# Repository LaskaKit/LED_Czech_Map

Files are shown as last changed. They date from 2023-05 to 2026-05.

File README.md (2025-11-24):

# Interaktivní LaskaKit LED Mapa ČR s adresovatelnými RGB LED

Domů, do zasedačky nebo do kanceláře, teplota nebo srážky, interaktivní mapa ČR s adresovatelnými RGB LED určitě překážky klást nebude. Měj přehled o aktuální situaci ať už je to teplota napříč Českou republikou nebo přicházející srážky, které pohodlně zobrazíš na této mapě. 

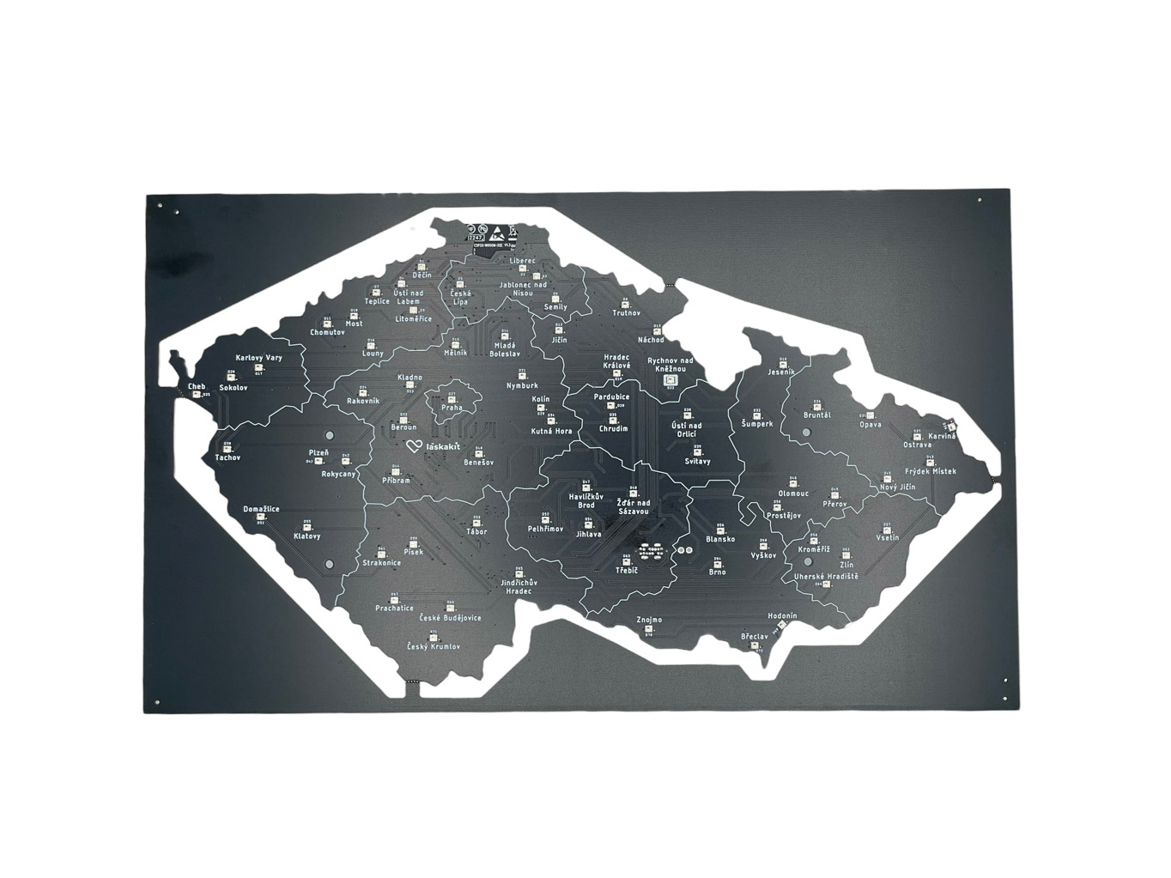
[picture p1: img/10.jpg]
Mapa


Na plošném spoji ve tvaru České republiky o velikosti cca 265x150mm najdeš desítky adresovatelných RGB LED, každá představuje jedno město v ČR.</br>
JSON: https://wiki.tmep.cz/doku.php?id=ruzne:led_mapa_okresu_cr

Seznam měst a pořadí RGB LED najdeš níže 
| LaskaKit ID | TMEP ID | Okres |
|:--:|:---:|:---|
| 25	| 1	| Cheb |
| 20	| 2	| Sokolov |
| 17	| 3	| Karlovy Vary |
| 11	| 4	| Chomutov |
| 16	| 5	| Louny |
| 10	| 6	| Most |
| 7	| 7 | Teplice |
| 9	| 8 | Litoměřice |
| 4	| 9 | Ústí nad Labem |
| 1 | 10 | Děčín |
| 5 | 11 | Česká Lípa |
| 2 | 12 | Liberec |
| 3 | 13 | Jablonec nad Nisou |
| 6 | 14 | Semily |
| 12 | 15 | Jičín |
| 8 | 16 | Trutnov |
| 13 | 17 | Náchod |
| 19 | 18 | Hradec Králové |
| 22 | 19 | Rychnov nad Kněžnou |
| 30 | 20 | Ústí nad Orlicí |
| 28 | 21 | Pardubice |
| 35 | 22 | Chrudim |
| 39 | 23 | Svitavy |
| 32 | 24 | Šumperk |
| 18 | 25 | Jeseník |
| 26 | 26 | Bruntál |
| 46 | 27 | Olomouc |
| 31 | 28 | Opava |
| 37 | 29 | Ostrava-město |
| 36 | 30 | Karviná |
| 43 | 31 | Frýdek-Místek |
| 45 | 32 | Nový Jičín |
| 57 | 33 | Vsetín |
| 49 | 34 | Přerov |
| 62 | 35 | Zlín |
| 58 | 36 | Kroměříž |
| 66 | 37 | Uherské Hradiště |
| 69 | 38 | Hodonín |
| 60 | 39 | Vyškov |
| 50 | 40 | Prostějov |
| 56 | 41 | Blansko |
| 64 | 42 | Brno-město |
| xx | 43 | Brno-venkov |
| 72 | 44 | Břeclav |
| 70 | 45 | Znojmo |
| 63 | 46 | Třebíč |
| 48 | 47 | Žďár nad Sázavou |
| 54 | 48 | Jihlava |
| 47 | 49 | Havlíčkův Brod |
| 52 | 50 | Pelhřimov |
| 65 | 51 | Jindřichův Hradec |
| 53 | 52 | Tábor |
| 68 | 53 | České Budějovice |
| 71 | 54 | Český Krumlov |
| 67 | 55 | Prachatice |
| 61 | 56 | Strakonice |
| 59 | 57 | Písek |
| 55 | 58 | Klatovy |
| 51 | 59 | Domažlice |
| 38 | 60 | Tachov |
| xx | 61 | Plzeň-sever |
| 41 | 62 | Plzeň-město |
| xx | 63 | Plzeň-jih |
| 42 | 64 | Rokycany |
| 24 | 65 | Rakovník |
| 23 | 66 | Kladno |
| 15 | 67 | Mělník |
| 14 | 68 | Mladá Boleslav |
| 21 | 69 | Nymburk |
| 29 | 70 | Kolín |
| 34 | 71 | Kutná Hora |
| 40 | 72 | Benešov |
| 44 | 73 | Příbram |
| 33 | 74 | Beroun |
| xx | 75 | Praha-západ |
| xx | 76 | Praha-východ |
| 27 | 77 | Praha |

Deska na které je osazen Wi-Fi a Bluetooth modul ESP32 obsahuje navíc i [uŠup konektor](https://blog.laskakit.cz/predstavujeme-univerzalni-konektor-pro-propojeni-modulu-a-cidel-%CE%BCsup/) pro připojení nejrůznějších čidel.

A jaké moduly to mohou být? Třeba čidlo [SCD41 pro měření CO2, teploty a vlhkosti vzduchu](https://www.laskakit.cz/laskakit-scd41-senzor-co2--teploty-a-vlhkosti-vzduchu/), čidla SHT41 [teploty a vlhkosti vzduchu](https://www.laskakit.cz/laskakit-sht40-senzor-teploty-a-vlhkosti-vzduchu/) a [čidla tlaku, teploty a vlhkosti vzduchu BME280](https://www.laskakit.cz/arduino-senzor-tlaku--teploty-a-vlhkosti-bme280/), [RTC Hodiny reálného času](https://www.laskakit.cz/laskakit-ds3231-orig--rtc-hodiny-realneho-casu/) s DS3231 nebo [OLED displej o velikosti 1.3" a rozlišení 128x64px](https://www.laskakit.cz/laskakit-oled-displej-128x64-1-3--i2c/?variantId=11903).

Deska LaskaKit LED Mapa ČR má osazen i vlastní programátor a není tak třeba mačkat tlačítka proto, aby se ESP32 naprogramovalo. Prostě jen připojíš USB-C kabel s počítačem a klikneš na "Nahrát".</br>
GPIO pin, který ovládá adresovatelné RGB LED je číslo 25 na ESP32. Adresovatelné RGB LED jsou zapojeny za sebou a díky už napsaným knihovnám je ovládání LEDek naprostá hračka. </br>

Mapa má i čtyři upevňovací otvory a navíc i rozšiřující konektor pro připojení třeba OLED displeje nebo čehokoliv jiného.

Díky popularitě této mapy vznikly nejrůznější zajímavé projekty - zobrazení teplot ze služby [TMEP.cz](https://tmep.cz/) ([vzorový kód najdeš tady](https://github.com/LaskaKit/LED_Czech_Map/tree/main/SW/tmep_okresy-cr-teplota)) nebo zobrazení srážek na základě dat z radaru.</br>
Kód je opět [na našem github](https://github.com/LaskaKit/LED_Czech_Map/tree/main/SW/CHMI_srazky). Kód má navíc možnosti nastavení zobrazení. 
Jednoduché zobrazení (vybereme pouze dominantní barva) nebo možnost přidání animace, zobrazení srážek před 30 minutami, 20, 10 a aktuální radarový obraz.

A to rozhodně není všechno! S touto mapou si můžeš zahrát hru "[Zachraň město! (github)](https://github.com/LaskaKit/LED_Czech_Map/tree/main/SW/Hra_Zachran_Mesto)". Správnou odpovědí uhasíš hořící město, tou špatnou začne hořet jiné.
Jednoduchou instalaci programu dokážeš díky naší [webové instalační stránce](https://www.laskakit.cz/navody-ke-zbozi/).

Máš jiný nápad? Sem s ním!

Mapu můžeš zakoupit na https://www.laskakit.cz/laskakit-interaktivni-mapa-cr-ws2812b/

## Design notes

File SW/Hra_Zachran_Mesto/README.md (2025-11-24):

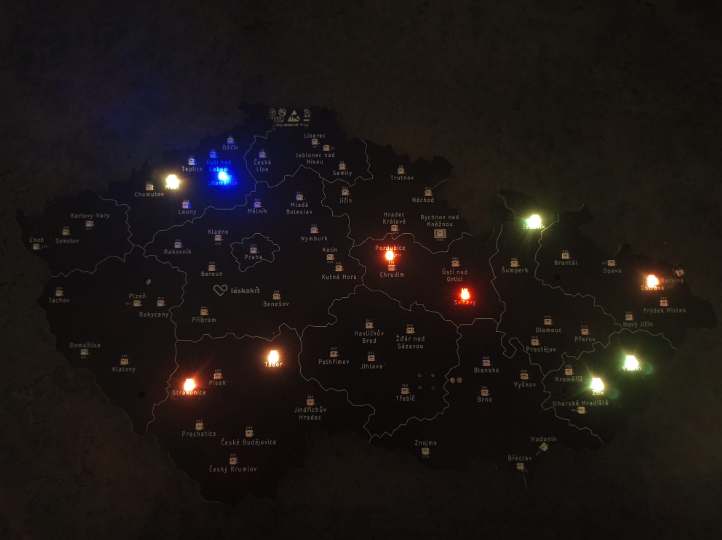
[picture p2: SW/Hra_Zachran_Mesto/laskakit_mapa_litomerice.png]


## Hra Zachraň město s vývojovou deskou Laskakit Interaktivní Mapa ČR

Tuto aplikaci jsme vytvořili jako zábavnou, interaktivní a naučnou hru pro použití s vývojovou deskou Laskakit Interaktivní Mapa ČR.

Hra začíná deseti městy, které jsou v plamenech a jen ty je můžeš zachránit! Ale pozor! Pokud odpovíš špatně, začne hořet další město!

### Využití
Využití této hry může být ve výuce na školách, kroužcích nebo třeba i mateřské škole, kde ovládat telefon bude učitel a odpovídat budou děti.
Položené otázky jsou jen ve vaší režii - jaké otázky tam zadáte, takové tam budete mít. Jediné, co je nutné, je dodržet formát otázek.
Chcete otázky ohledně matematiky pro první stupeň? Jasně! Zeměpis? Jasně! Čeština? Samozřejmě. 

Díky této interaktivní pomůcce může být i výuka zajímavější a zábavnější!

Tato aplikace využívá interaktivní mapu ČR od Laskakit.cz. Hráč na mobilním telefonu, tabletu nebo počítači musí skrze webový prohlížeč odpovídat na otázky, dokud neuhasí všechna města.

### Začátek hry

Po zapnutí vytvoří deska vlastní Access Point. Připoj se přes tvůj telefon k WiFi "LaskaKit_MapaCR", v prohlížeči zadej IP adresu 192.168.4.1. Tam můžeš zadat jméno a heslo k tvé WiFi.
Po restartu se ti v Serial Terminalu (Arduino, Yat, Putty; rychlost 115200 Bd) zobrazí přidělená IP adresa. V prohlížeči zadej tvou IP adresu a můžeš přidat otázky a začít hrát.

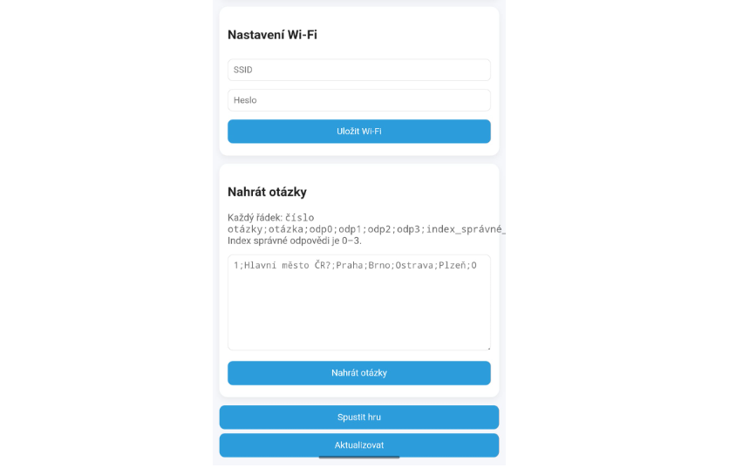
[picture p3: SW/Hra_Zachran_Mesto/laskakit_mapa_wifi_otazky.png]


Vývojová deska založená na ESP32 si otázky neukládá do trvalé paměti. Po každém restartu je nutné zadat sadu otázek. Čip si ale pamatuju zadané jméno a heslo k WiFi. 
Pokud se k ní nepřipojí, vytvoří si vlastní s názvem "Laskakit_MapaCR".

### Formát otázek
Číslo otázky; Otázka; Odpověď0; Odpověď1; Odpověď2; Odpověď3; Index správné odpovědi 0–3

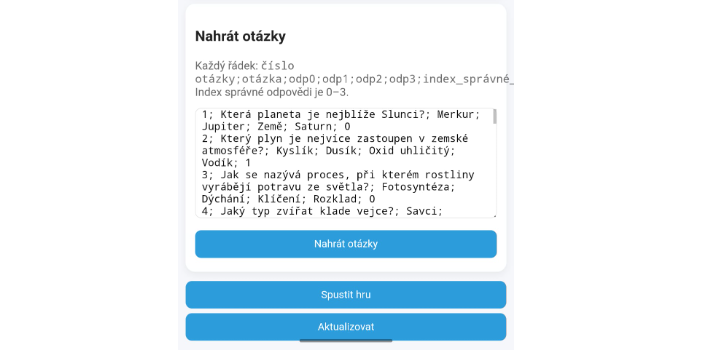
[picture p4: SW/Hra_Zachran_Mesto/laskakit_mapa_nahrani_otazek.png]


Pokud chceš zadat vlastní otázky a nevyužiješ například AI (ChatGPT, Perplexity atp), otázky můžeš napsat v excelu a vyexportovat jako CSV s oddělovačem ";".

### Tip: Prompt (zadání) pro chatGPT, Perplexity atp
Příklad: Vytvoř 30 otázek. Otázky se musí týkat přírodovědy pro druhý stupeň základní školy. Vedle správné odpovědi na otázku přidej i tři nesprávné odpovědi. 
Správnou odpověď na jiné místo odpovědi.
Číslo otázky; Otázka; Odpověď0; Odpověď1; Odpověď2; Odpověď3; Číslo správné odpovědi 0–3

Prompt (zadání) si samozřejmě můžeš upravit dle vlastních potřeb.

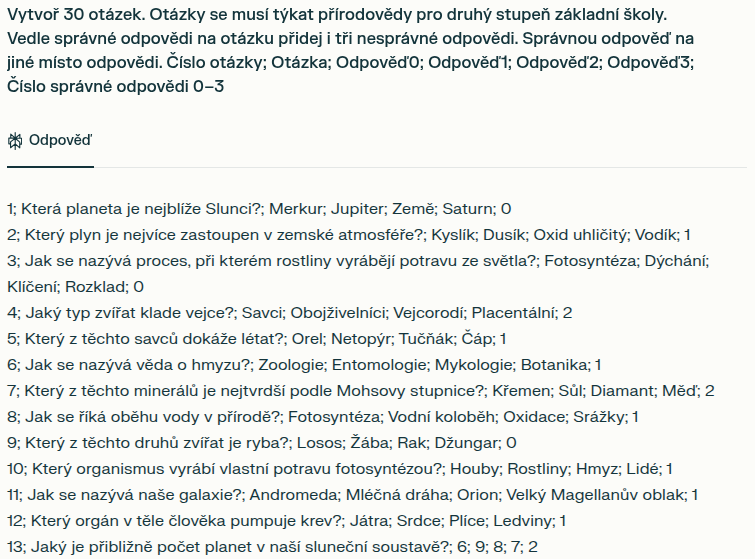
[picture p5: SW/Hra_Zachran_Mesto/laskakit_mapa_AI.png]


Kód provádí základní kontrolu zadaných otázek - zda oddělovač je správně a počet oddělovačů odpovídá a také index správné odpovědi je v rozsahu.

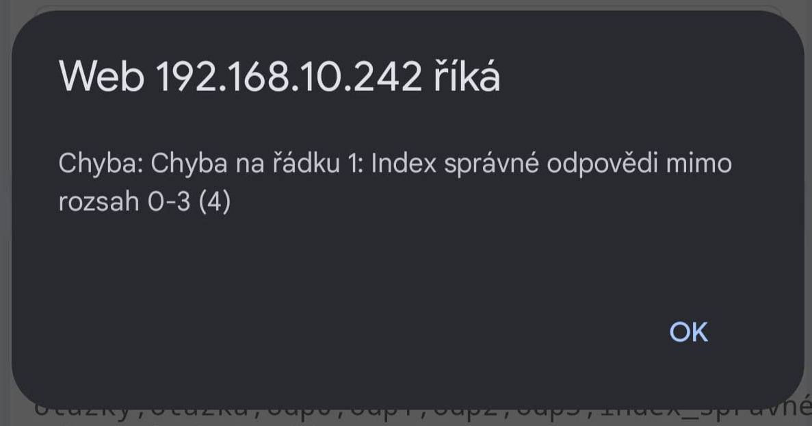
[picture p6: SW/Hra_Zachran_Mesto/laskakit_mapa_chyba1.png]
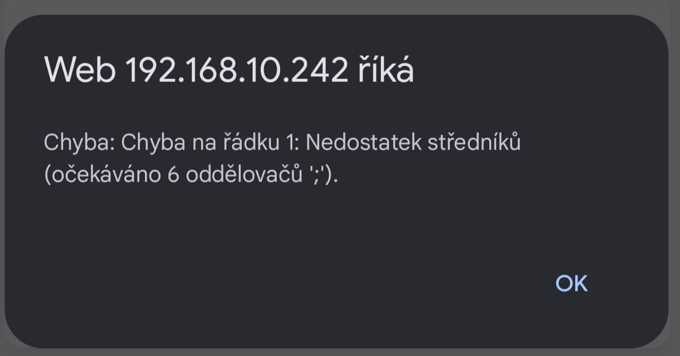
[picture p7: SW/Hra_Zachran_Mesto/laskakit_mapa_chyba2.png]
 

### Kód - naprogramování bez programování
Abys nemusel stahovat Arduino IDE, knihovny a kompilovat kód, můžeš jednoduše nahrát už hotový kód do desky skrze naši webovou stránku.
Připoj USB kabel do Laskakit RGB mapy a k počítači, přejdi na tuto stránku https://www.laskakit.cz/navody-ke-zbozi/ a klikni na "Instalovat" a drž se pokynů.
Po naprogramování pokračuj k záložce "Návod" - tam mapu připojíš k Wi-Fi a nahraješ otázky.

### Potřebné knihovny
https://github.com/adafruit/Adafruit_NeoPixel

### Potřebujete koupit
https://www.laskakit.cz/laskakit-interaktivni-mapa-cr-ws2812b/

### Návod

Na začátku hry se vybere náhodně 10 měst

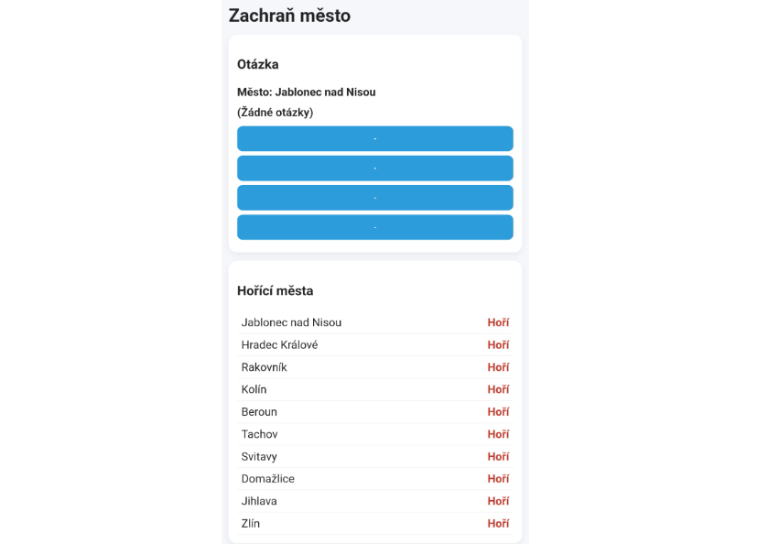
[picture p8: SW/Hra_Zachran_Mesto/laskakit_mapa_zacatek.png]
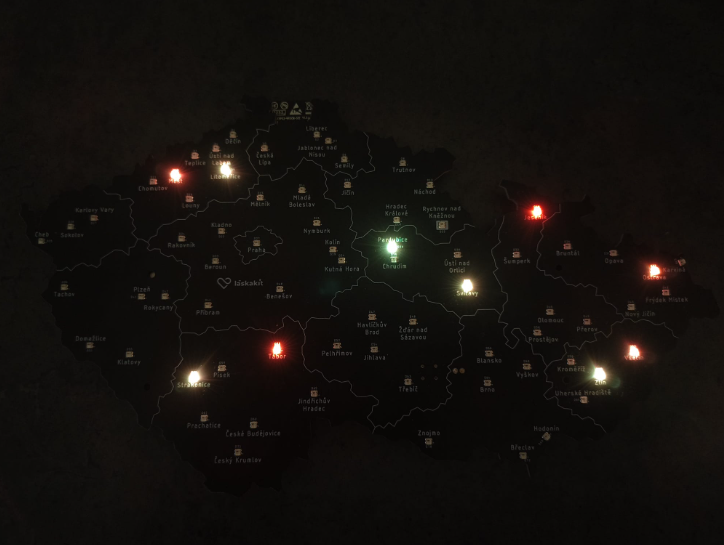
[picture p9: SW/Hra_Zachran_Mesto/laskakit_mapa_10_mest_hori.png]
 

Při správné odpovědi se uhasi jedno z měst o které se hraje (Litoměřice)

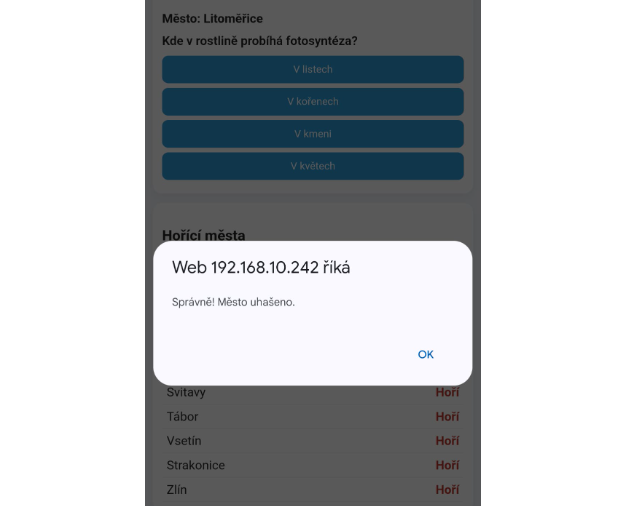
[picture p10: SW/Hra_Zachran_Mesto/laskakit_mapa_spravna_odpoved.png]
 

Při špatné odpovědi naopak začne jiné, náhodně vybrané město, hořet (Břeclav)

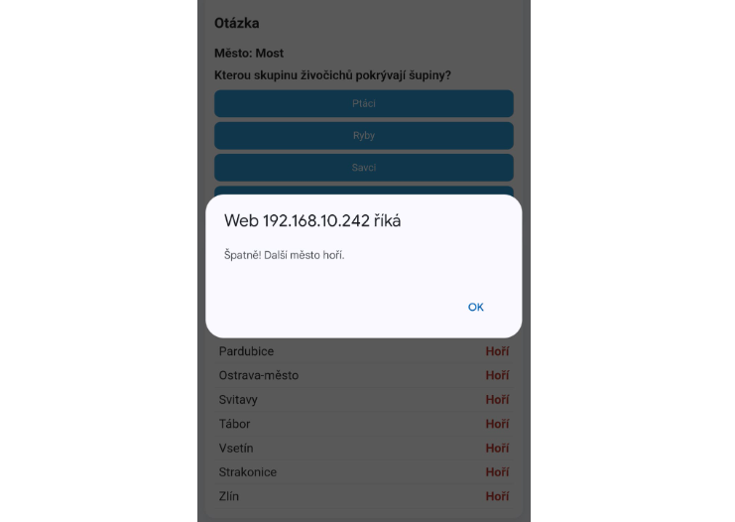
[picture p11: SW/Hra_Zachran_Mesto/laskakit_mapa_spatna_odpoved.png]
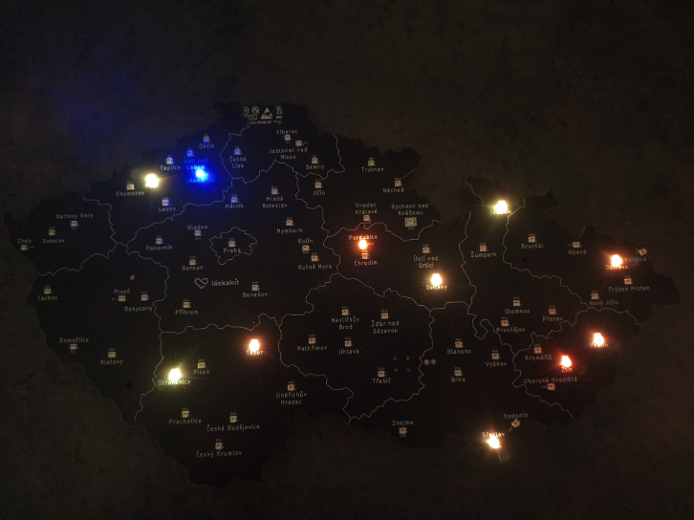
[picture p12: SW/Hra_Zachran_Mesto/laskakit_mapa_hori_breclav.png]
 

Při všech správně zodpovězených vyhraješ a můžeš začít hrát znovu a zadat nové otázky!

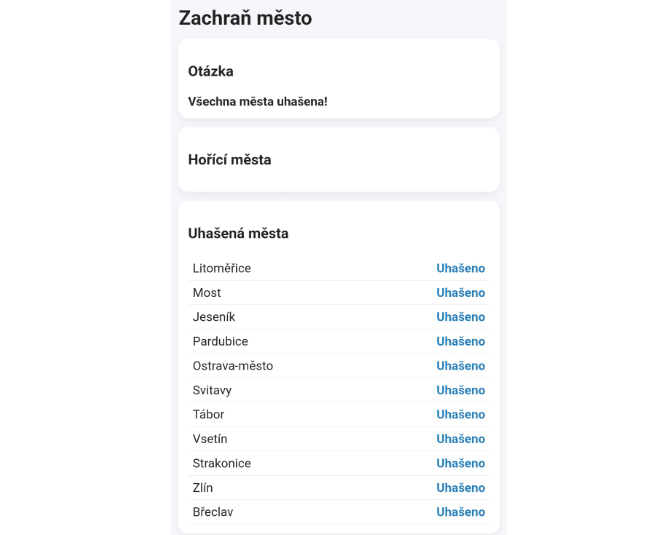
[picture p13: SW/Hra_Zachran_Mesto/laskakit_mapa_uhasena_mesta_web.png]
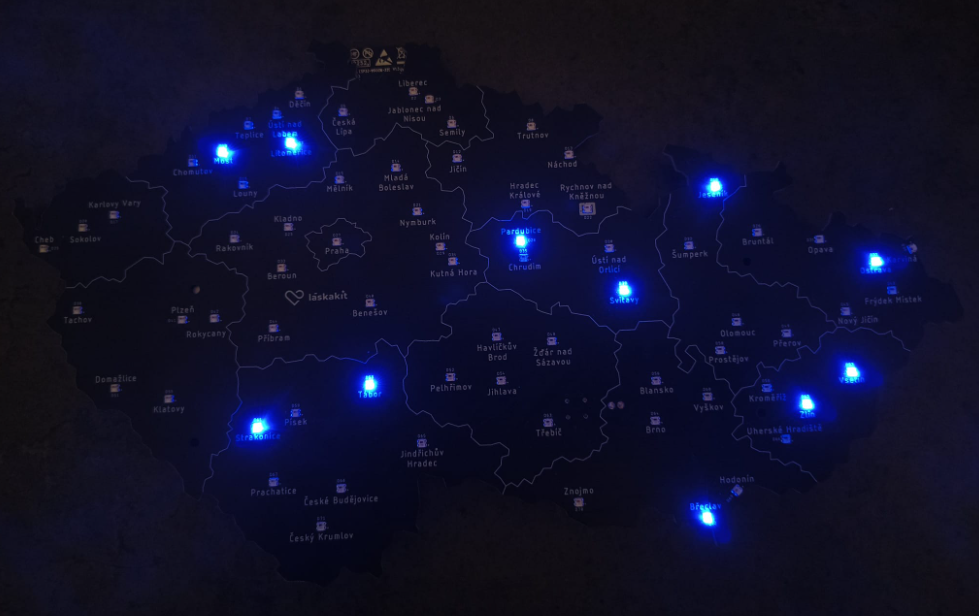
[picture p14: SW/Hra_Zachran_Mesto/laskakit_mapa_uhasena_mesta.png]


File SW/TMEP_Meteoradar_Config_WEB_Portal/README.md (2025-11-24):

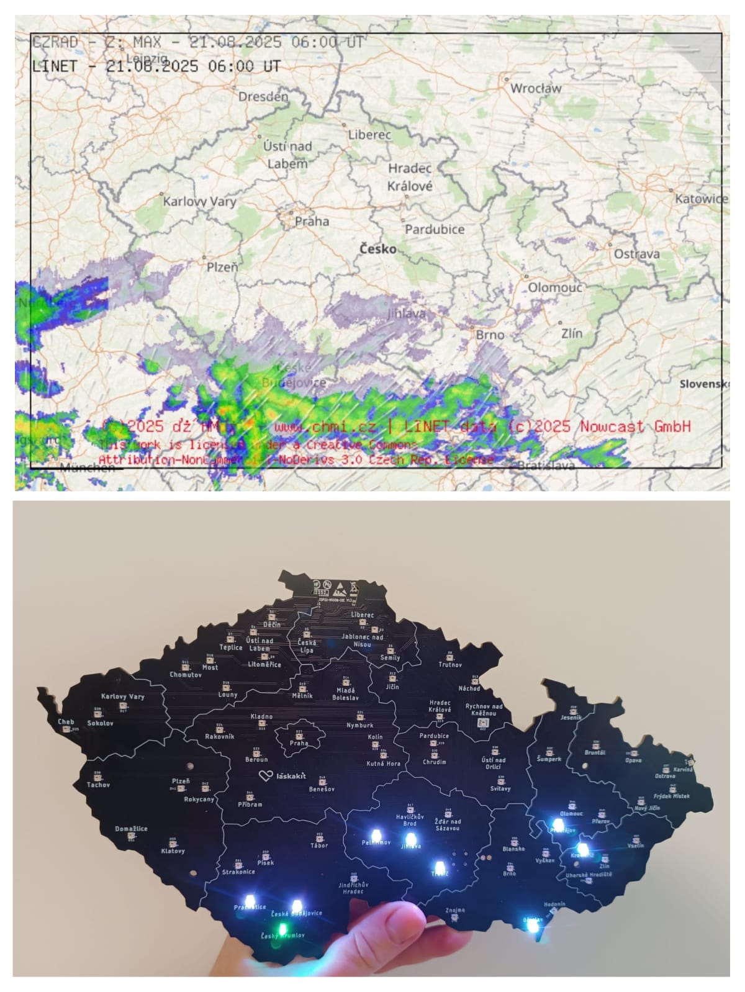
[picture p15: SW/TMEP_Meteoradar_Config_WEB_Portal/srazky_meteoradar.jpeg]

Zobrazeni Meteoradaru

Tento vzorový kód představuje slouží k vizualizaci environmentálních dat pomocí interaktivní LED mapy České republiky.
LaskaKit Interaktivní Mapa ČR nabízí uživatelům pohodlnou webovou konfiguraci přes WiFi. 

## Hlavní funkce a schopnosti
### Zobrazení dat na LED mapě
Na mapě je 72 adresovatelných LED diod reprezentující vybraná města v ČR. LED diody indikují hodnoty různých environmentálních parametrů — teplotu, vlhkost, tlak či prašnost — pomocí barevného kódování. Barvy se dynamicky mění podle aktuálních hodnot, což umožňuje rychlou vizuální orientaci v lokalizovaných podmínkách.
Vstupní data jsou použita z projektu [TMEP.cz](https://tmep.cz/).

### Podpora Meteoradaru
Kromě základních meteorologických veličin lze pro dané oblasti zobrazit i speciální datovou vrstvu „meteoradar“, která ukazuje srážky. LED diody v tomto režimu mění barvu podle dat získaných z meteoradaru a nepoužívají standardní škálu parametrů, což umožňuje uživatelům detailnější pohled na aktuální počasí.
Původní projekt i s popisem funkce najdete na [zive.cz](https://www.zive.cz/clanky/naprogramovali-jsme-radarovou-mapu-ceska-ukaze-kde-prave-prsi-a-muzete-si-ji-dat-i-na-zed/sc-3-a-222111/default.aspx)

### Webová konfigurační stránka přes WiFi
Zařízení vytváří vlastní WiFi síť, do které se uživatel připojí a přes webový prohlížeč nastaví parametry jako SSID a heslo WiFi sítě, vybraný meteorologický parametr pro vizualizaci, jas LED, interval aktualizací dat a jiné. Tato konfigurace je přístupná z libovolného zařízení schopného připojit se k WiFi.
Pokud se ESP32 nedokáže připojit k Wi-Fi (první zapnutí či výpadek klientské Wi-Fi), ESP32 vytvoří Access Point s názvem Wi-Fi sítě "Laskakit-MapaCR". Skrze (například) mobilní telefon se připojíte k této Wi-Fi síti a ve webovém prohlížeči (například google chrome) zadáte adresu 192.168.4.1.
Na této stránce můžete upravit výše zmíněné údaje - SSID a heslo vaší Wi-Fi sítě, zobrazený parametr atp. Po restartu se Interaktivní mapa připojí do vaší Wi-Fi sítě. Zjistíte si (například z routeru, Terminálu (Putty, YAT atp, rychlost 115 200Bd) ) IP adresu tohoto zařízení a opět si můžete upravovat konfiguraci ve webovém prohlížeči - stačí zadat IP adresu zařízení (například 192.168.10.242 - vy budete mít jinou)

### Okamžité aplikování změn bez nutnosti restartu
Změny parametrů se většinou projeví ihned, například úprava jasu LED nebo změna sledovaného parametru bez nutnosti restartu zařízení. Restart je nutný pouze při změně WiFi SSID nebo hesla, kdy je potřeba připojení znovu inicializovat.

### Statistické přehledy parametrů přímo na webu
Webová stránka zobrazuje u aktuálně zvoleného parametru statistiky: minimální, průměrnou a maximální hodnotu. Tyto hodnoty jsou doplněny barevným značením shodným s barvou LED indikující hodnoty na mapě, což zvyšuje přehlednost a vizuální korelaci s naměřenými daty.
Toto zobrazení přehledu není v režimu meteoradaru dostupné.

### Podpora automatických aktualizací dat
Data jsou pravidelně stahována z veřejných JSON zdrojů s intervalem nastavitelným uživatelem (uvedené jsou defaultně 60 sekund). Díky tomu je mapa vždy aktuální a odráží změny počasí či kvality ovzduší v reálném čase.

## Možné využití
### Domácí či komunitní monitorování počasí a kvality ovzduší
Uživatelé mohou snadno sledovat meteorologické podmínky ve svém okolí nebo ve vybraných částech ČR díky vizuální LED indikaci a přehledným statistikám.

### Vzdělávací účely a demonstrace datové vizualizace
Projekt může sloužit jako praktický nástroj pro výuku práce s IoT zařízeními, senzory, zpracováním dat a webovým ovládáním embedded systémů.

### Podpora environmentálních projektů a komunitních senzorových sítí
Kód umožňuje jednoduchou integraci s volně dostupnými daty a škálovatelnost pro zobrazování více typů měřených veličin, což ocení i projekty zaměřené na sledování kvality ovzduší nebo klimatu.

### Shrnutí
Celkově jde o sofistikované zařízení postavené na platformě ESP32, které vkusně kombinuje vizuální LED mapu s robustní webovou konfigurací a četnými užitečnými funkcemi. Díky tomu nabízí uživatelům snadné a flexibilní prostředky pro monitorování a zobrazení environmentálních dat, a to jak pro osobní použití, tak i pro širší komunitní projekty.

## Interaktivní mapu můžete objednat na [https://www.laskakit.cz/laskakit-interaktivni-mapa-cr-ws2812b/](https://www.laskakit.cz/laskakit-interaktivni-mapa-cr-ws2812b/)

Webstránka a první zapnutí (nebo nedostupnost klientské Wi-Fi sítě. SSID Laskakit-MapaCR, IP adresa 192.168.4.1
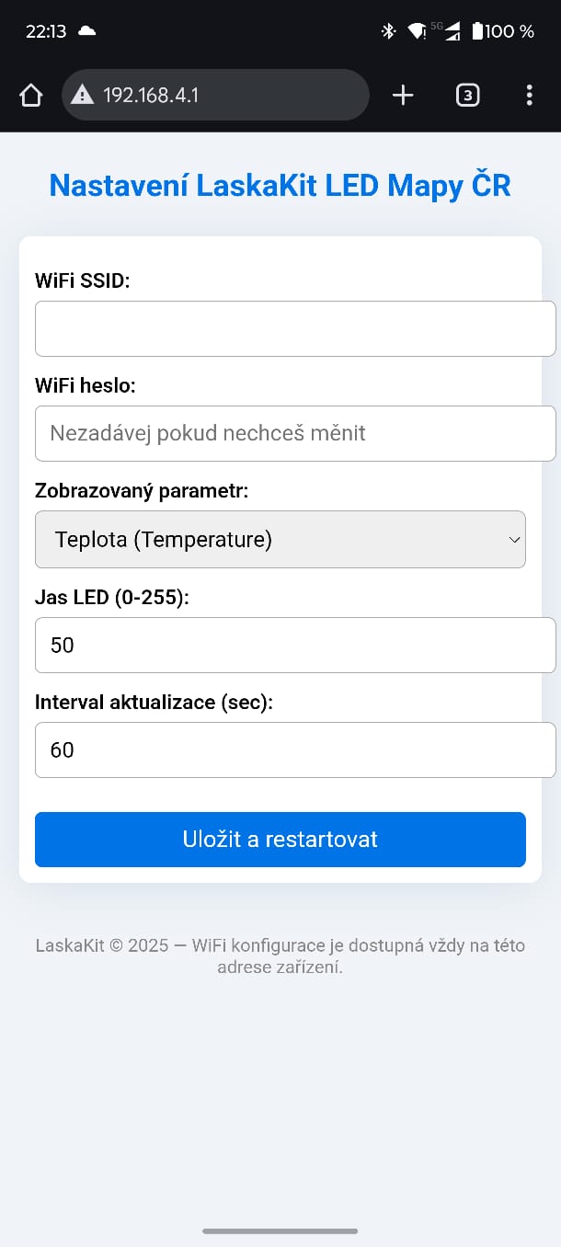
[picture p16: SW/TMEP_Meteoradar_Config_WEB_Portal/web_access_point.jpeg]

Webstránka - první nastavení

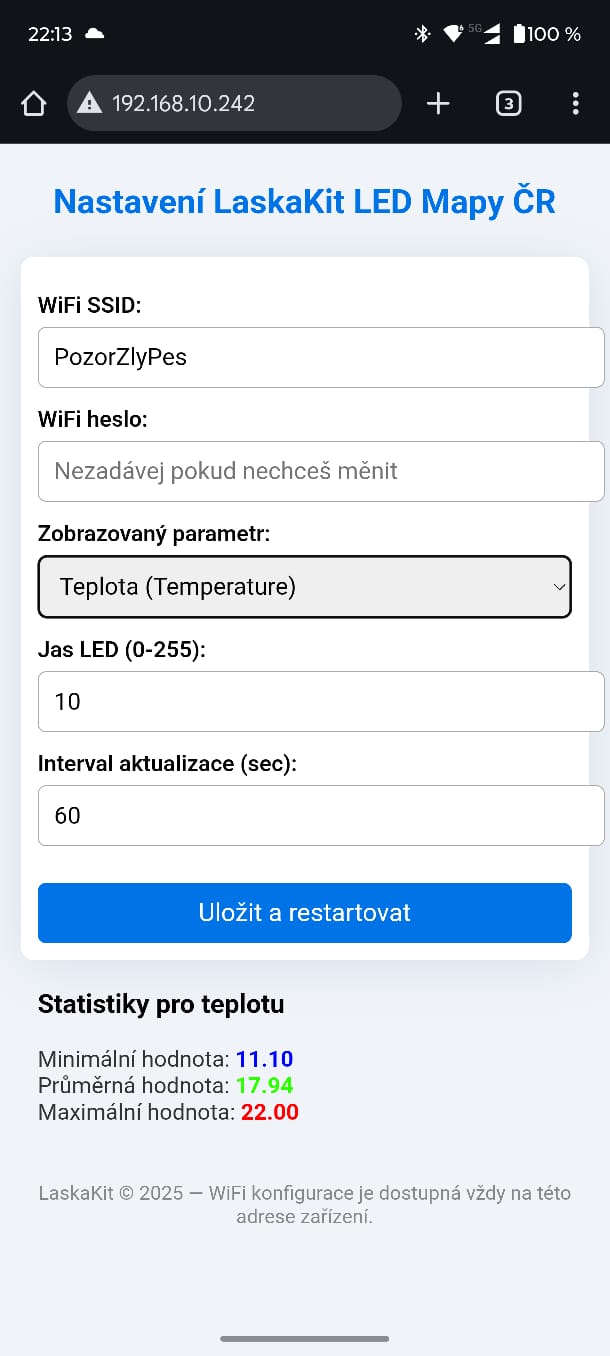
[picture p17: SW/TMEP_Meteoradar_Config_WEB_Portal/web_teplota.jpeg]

Webstránka teplota

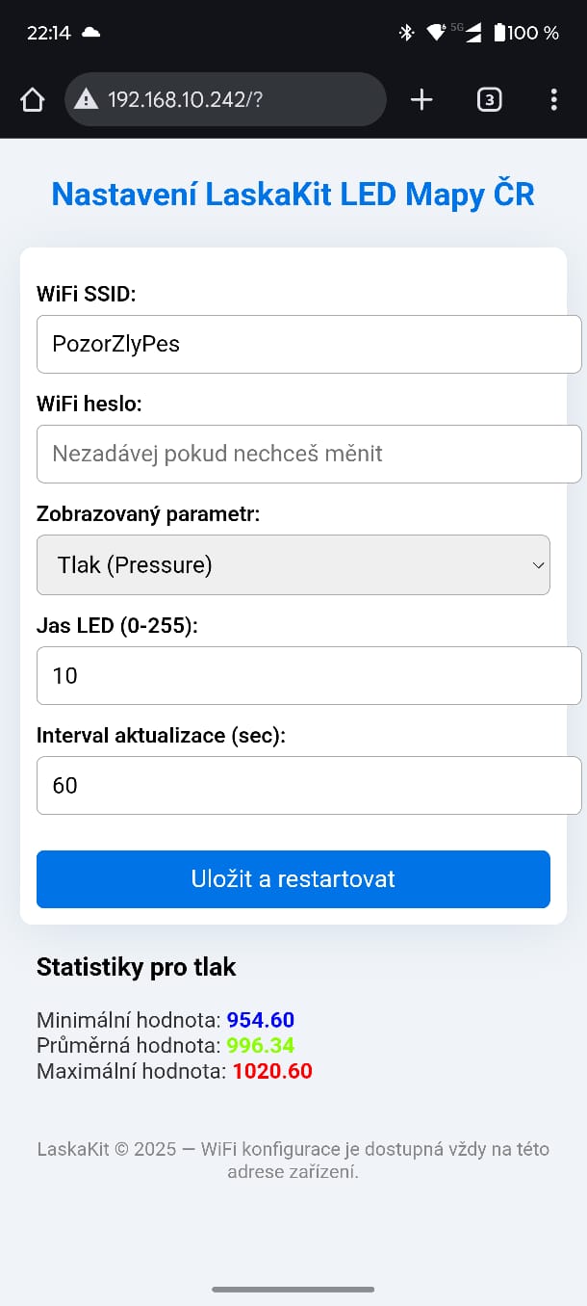
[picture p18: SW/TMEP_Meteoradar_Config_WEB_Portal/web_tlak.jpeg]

Webstránka tlak

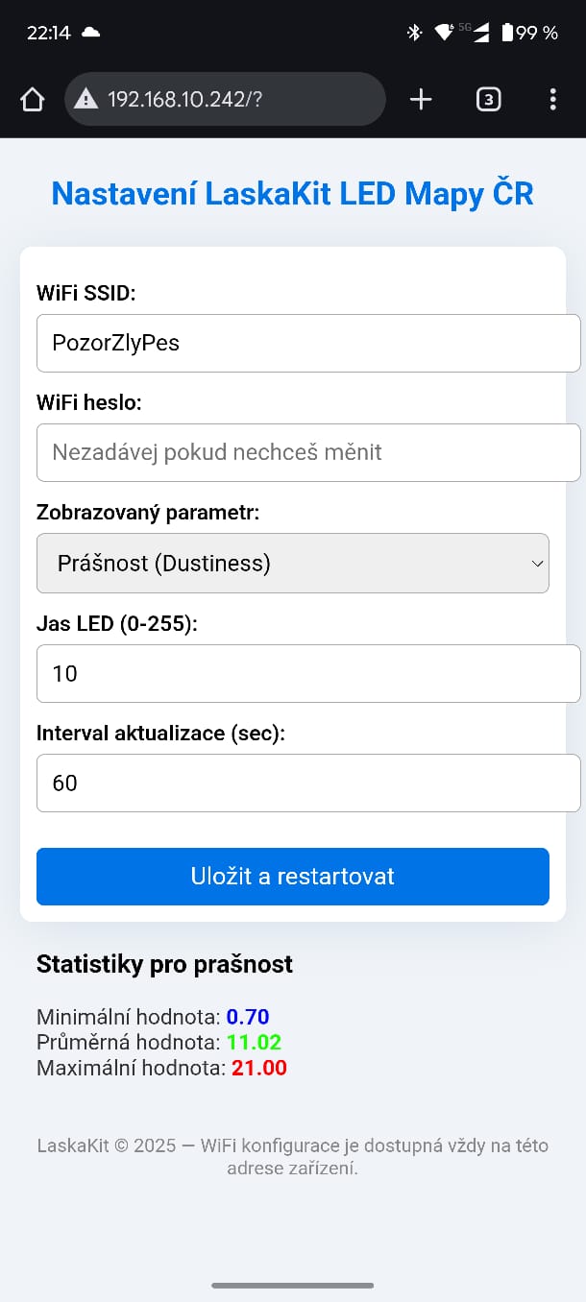
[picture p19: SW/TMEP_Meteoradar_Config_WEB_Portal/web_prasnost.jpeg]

Webstránka prasnost

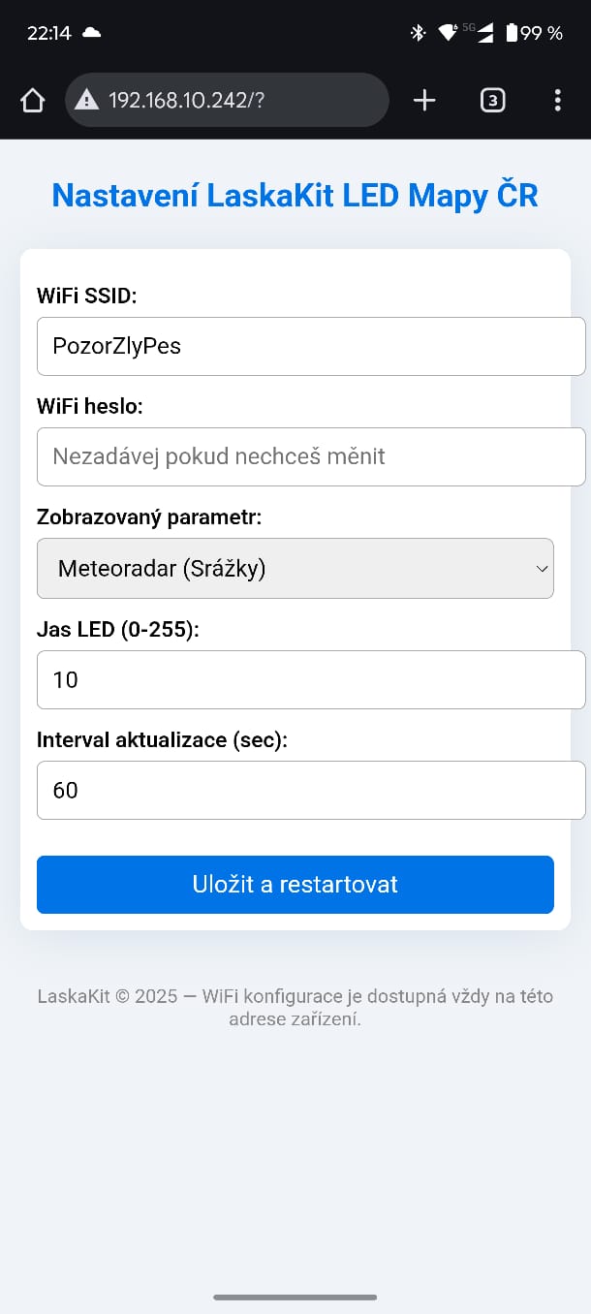
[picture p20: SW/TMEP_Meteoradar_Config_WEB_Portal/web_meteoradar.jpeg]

Webstránka meteoradar

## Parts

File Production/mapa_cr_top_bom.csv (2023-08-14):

Comment | Designator | Footprint | LCSC Part #
WS2812B | D45 D1 D2 D3 D4 D5 D6 D7 D8 D9 D10 D11 D12 D13 D14 D15 D16 D17 D18 D19 D20 D21 D22 D23 D24 D25 D26 D27 D28 D29 D30 D31 D32 D33 D34 D35 D36 D37 D38 D39 D40 D41 D42 D43 D44 D46 D47 D48 D49 D50 D51 D52 D53 D54 D55 D56 D57 D58 D59 D60 D61 D62 D63 D64 D65 D66 D67 D68 D69 D70 D71 D72 | WS2812B_2020 | C965555
1k | R4 | R0402
4 7uF | C8 | C0603 | C19666
5k1 | R8 R9 | R0402
10k | R1 R2 R3 R5 R6 R7 | R0402
22uF | C13 C61 | C0603
47uF | C2 | C0603
100n | C4 C5 C6 C7 C9 C10 C11 C12 C14 C15 C16 C17 C18 C19 C20 C21 C22 C23 C24 C25 C26 C27 C28 C29 C30 C31 C33 C34 C35 C36 C37 C38 C39 C40 C41 C42 C43 C44 C45 C46 C47 C48 C49 C50 C51 C52 C53 C54 C55 C56 C57 C58 C59 C60 C62 C63 C64 C65 C66 C68 C69 C70 C71 C72 C73 C74 C75 C76 C77 C78 C79 C80 C81 C82 | C0402
100nF | C1 C3 | C0402
100uF | C32 C67 | C1206
0805L050 | F1 | 0805L | C66452
BSS138 | Q1 | SOT23-3 | C78284
CH9102F | IC3 | QFN24-4X4
EN button | RESET | TS1088R02026 | C455280
ESP32-WROOM-32E | IC1 | ESP32WROOM32E | C701343
JST-SH-4_VERT | J1 | 1X04_1MM_RA_VERT | C371588
ME6211C33M5G | IC2 | SOT23-5
MMDT3904 | Q2 | SC70-6 | C268586
918-418K2022Y40000 | J2 | USB-C_VERT_SMD | C168704
X6521WVS-2x16H-C60D74 | J3 | 2X16SMD | C2884025

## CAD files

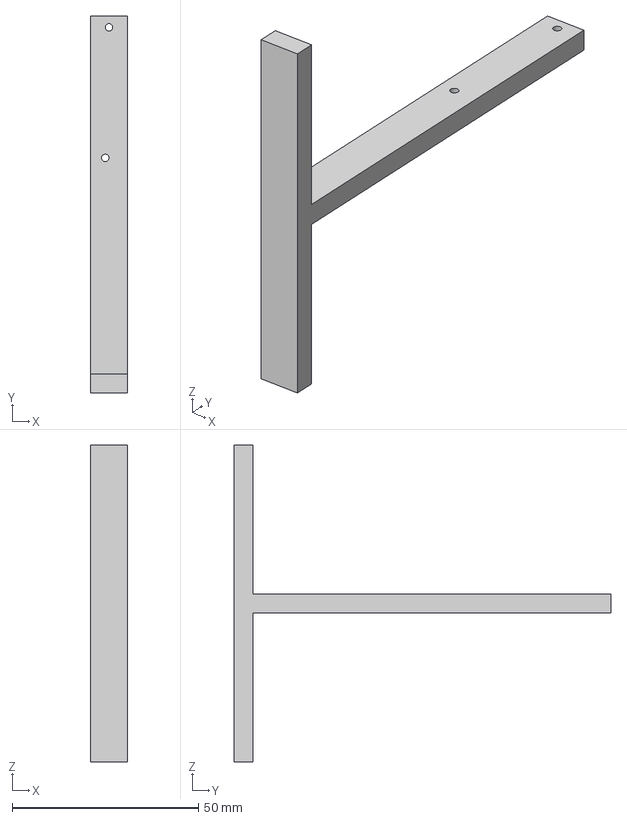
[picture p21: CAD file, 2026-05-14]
3D/noha.step
10.0 x 101.0 x 85.0 mm

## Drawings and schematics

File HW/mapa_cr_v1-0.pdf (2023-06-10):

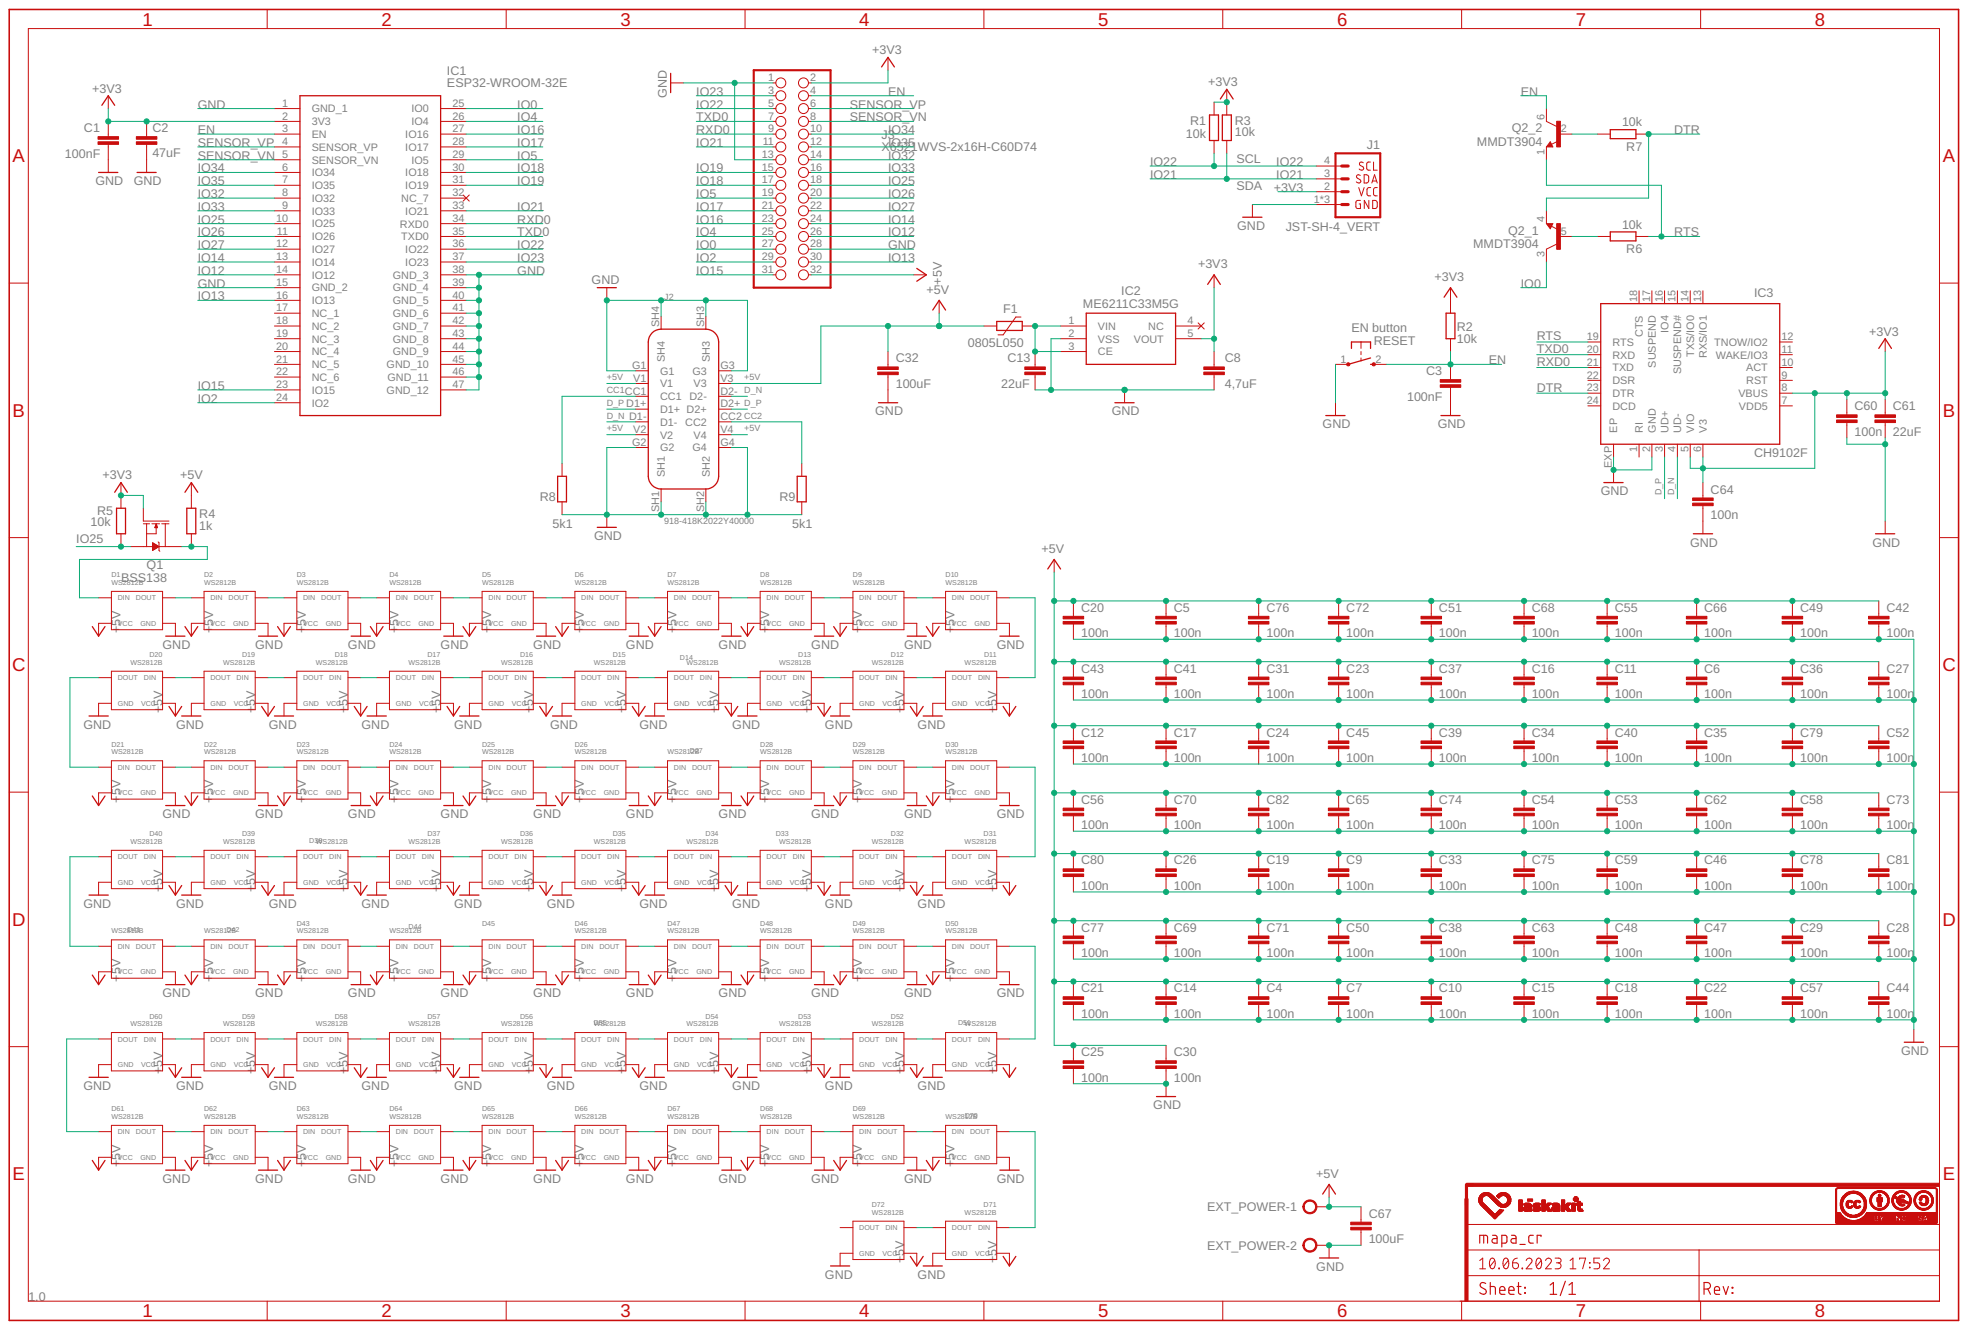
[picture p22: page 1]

BSS138
DIN DOUT VCC GND

DOUT DIN GND VCC

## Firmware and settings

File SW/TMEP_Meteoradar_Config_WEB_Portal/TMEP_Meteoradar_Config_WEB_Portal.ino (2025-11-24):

/*
 * Interaktivni mapa CR s webovym portalem pro snadne nastaveni Wi-Fi site 
 * a zobrazeni ruznych dat - teplota, vlhkost, tlak, prasnost a meteoradar na mape.
 *
 * Po prvnim zapnuti ESP32 vytvori Access Point s SSID Laskakit-MapaCR, pripojte se na tuto WiFi a ve
 * vasem webovem prohlizeci zadejte IP adresu 192.168.4.1, tam nastavte SSID a heslo vasi domaci Wi-Fi site,
 * Po restartu a pripojeni do vasi Wi-Fi site si mapa nacte vybrana data a zobrazi. Upravu zobrazeni dat, jasu nebo
 * intervalu aktualizace muzete provest pres webovy prohlizec kam napisete IP adresu zarizeni.
 * Tu zjistite napriklad z vaseho routeru (jakou IP adresu router mape pridelil) nebo z Terminalu (Putty, YAT, Arduino)
 * rychlost 115 200 Bd
 *
 *  Knihovny:
 * https://arduinojson.org/
 * https://github.com/adafruit/Adafruit_NeoPixel
 *
 * Kompilace
 * Tools -> Board -> ESP32 Dev Module
 *
 * Hardware: https://www.laskakit.cz/laskakit-interaktivni-mapa-cr-ws2812b/
 *
 * Laskakit (2025)
 */


#include <WiFi.h>
#include <HTTPClient.h>
#include <WebServer.h>
#include <ArduinoJson.h>
#include <Adafruit_NeoPixel.h>
#include <Preferences.h>

#define LEDS_COUNT 72     // počet LED diod na mapě
#define LEDS_PIN 25       // pin pro připojení LED pásku

Preferences preferences;  // pro ukládání nastavení
WebServer server(80);    // webový server na portu 80

Adafruit_NeoPixel strip(LEDS_COUNT, LEDS_PIN, NEO_GRB + NEO_KHZ800); // LED pás konfigurace

// Klíče pro uložení konfigurace do Preferences
const char* KEY_SSID = "ssid";
const char* KEY_PASS = "password";
const char* KEY_PARAM = "param";
const char* KEY_BRIGHT = "brightness";
const char* KEY_UPDATE = "update";

// URL pro získání JSON dat
const char* JSON_URL_MAIN = "http://cdn.tmep.cz/app/export/okresy-cr-vse.json";
const char* JSON_URL_METEORADAR = "http://tmep.cz/app/export/okresy-srazky-laskakit.json";

// Proměnné pro uložené hodnoty
char storedSSID[32] = "";
char storedPassword[64] = "";
char selectedParameter[16] = "h1";  // výchozí parametr - teplota
int brightness = 50;                // jas LED
unsigned long timerDelay = 60000;  // interval aktualizace v ms

float TMEPDistrictValues[77];       // pole hodnot pro jednotlivé okresy

// Mapování indexů okresů na pozice LED diod
int TMEPDistrictPosition[72] = {
  9, 11, 12, 8, 10, 13, 6, 15, 7, 5, 3, 14, 16, 67, 66, 4, 2, 24, 17, 1, 68, 18, 65, 64, 0,
  25, 76, 20, 69, 19, 27, 23, 73, 70, 21, 29, 28, 59, 22, 71, 61, 63, 30, 72, 31, 26, 48,
  46, 33, 39, 58, 49, 51, 47, 57, 40, 32, 35, 56, 38, 55, 34, 45, 41, 50, 36, 54, 52, 37,
  44, 53, 43
};

unsigned long lastTime = 0;  // čas poslední aktualizace
bool wifiConnected = false;  // připojeno k WiFi
int color;                   // proměnná pro barvu LED
int first_time = 0;          // příznak pro první spuštění

// Struktura pro statistiky hodnot a odpovídající barvy LED
struct StatColor {
  float minValue;
  float avgValue;
  float maxValue;
  uint32_t minColor;
  uint32_t avgColor;
  uint32_t maxColor;
};

// Pomocná funkce mapující hodnotu na barvu dle odstínu (Hue) LED
int mapValueToHue(float val, float minVal, float maxVal) {
  if (maxVal == minVal) return 85;  // střední barva, když všechny hodnoty stejné
  int color = map(val, minVal, maxVal, 170, 0);
  if (color < 0) color = 0;
  if (color > 170) color = 170;
  return color;
}

// Převod 32bitové barvy RGB na hex string pro HTML stylování
String colorToHex(uint32_t c) {
  uint8_t r = (c >> 16) & 0xFF;
  uint8_t g = (c >> 8) & 0xFF;
  uint8_t b = c & 0xFF;
  char buf[8];
  snprintf(buf, sizeof(buf), "#%02X%02X%02X", r, g, b);
  return String(buf);
}

// Vypočítá min, průměr a max hodnotu z pole JSON dat a příslušné barvy LED
StatColor calculateStatsAndColors(JsonArray data, const char* param) {
  float minV = 1e6;
  float maxV = -1e6;
  float sumV = 0;
  int count = 0;

  // Průchod pro zjištění min a max hodnoty
  for (JsonObject obj : data) {
    if (obj.containsKey(param)) {
      float val = obj[param];
      if (val < minV) minV = val;
      if (val > maxV) maxV = val;
    }
  }

  // Výpočet součtu a počtu hodnot pro průměr
  for (JsonObject obj : data) {
    if (obj.containsKey(param)) {
      float val = obj[param];
      sumV += val;
      count++;
    }
  }
  float avgV = (count > 0) ? (sumV / count) : 0.0;

  // Převedení hodnot na barvu ve škále LED (HSV)
  uint32_t minCol = strip.ColorHSV(mapValueToHue(minV, minV, maxV) * 256);
  uint32_t avgCol = strip.ColorHSV(mapValueToHue(avgV, minV, maxV) * 256);
  uint32_t maxCol = strip.ColorHSV(mapValueToHue(maxV, minV, maxV) * 256);

  return StatColor{minV, avgV, maxV, minCol, avgCol, maxCol};
}

void setup() {
  Serial.begin(115200);
  delay(10);

  // Inicializace preferencí pro uložení nastavení
  preferences.begin("LaskaKit", false);

  // Načtení uložených hodnot z paměti
  preferences.getString(KEY_SSID, "").toCharArray(storedSSID, sizeof(storedSSID));
  preferences.getString(KEY_PASS, "").toCharArray(storedPassword, sizeof(storedPassword));
  String param = preferences.getString(KEY_PARAM, "h1");
  param.toCharArray(selectedParameter, sizeof(selectedParameter));
  brightness = preferences.getInt(KEY_BRIGHT, 50);
  timerDelay = preferences.getInt(KEY_UPDATE, 60) * 1000UL;

  // Inicializace LED pásku
  strip.begin();
  strip.setBrightness(brightness);
  strip.show();

  // Připojení k WiFi nebo spuštění AP podle uložených dat
  if (strlen(storedSSID) > 0) {
    setupWiFi();
  } else {
    startAP();
  }
}

void loop() {
  // Webový server musí zpracovávat požadavky stále
  server.handleClient();

  // Pravidelné aktualizace dat a zobrazení, popř. při prvním spuštění
  if (wifiConnected) {
    if ((millis() - lastTime) > timerDelay || first_time == 0) {
      fetchAndDisplayData();
      lastTime = millis();
      first_time = 1;
    }
  }
}

void setupWiFi() {
  Serial.printf("Připojuji se k WiFi: '%s'\n", storedSSID);

  WiFi.mode(WIFI_STA);
  WiFi.begin(storedSSID, storedPassword);

  unsigned long start = millis();
  while (WiFi.status() != WL_CONNECTED && millis() - start < 15000) {
    delay(500);
    Serial.print(".");
  }
  Serial.println();

  if (WiFi.status() == WL_CONNECTED) {
    Serial.printf("Připojeno! IP adresa: %s\n", WiFi.localIP().toString().c_str());
    wifiConnected = true;
  } else {
    Serial.println("Nepodařilo se připojit! Spouštím AP...");
    wifiConnected = false;
    startAP();
  }

  // Nastavení obsluhy HTTP cest
  server.on("/", HTTP_GET, handleRoot);
  server.on("/save", HTTP_POST, handleSave);
  server.onNotFound(handleNotFound);
  server.begin();
}

void startAP() {
  // Spustí WiFi AP (Access Point) s názvem LaskaKit-Config pro konfiguraci zařízení
  WiFi.mode(WIFI_AP);
  WiFi.softAP("LaskaKit-MapaCR");
  Serial.print("IP adresa AP: ");
  Serial.println(WiFi.softAPIP());

  wifiConnected = false;

  // HTTP cesty i v AP režimu
  server.on("/", HTTP_GET, handleRoot);
  server.on("/save", HTTP_POST, handleSave);
  server.onNotFound(handleNotFound);
  server.begin();

  // Zhasnutí LED při konfiguraci
  strip.clear();
  strip.show();
}

void handleRoot() {
  // Funkce generující hlavní stránku s formulářem i s výpisem statistik

  WiFiClient client;
  HTTPClient http;
  // URL se liší podle typu zobrazeného parametru (meteoradar má vlastní data)
  const char* currentURL = (strcmp(selectedParameter, "meteoradar") == 0) ? JSON_URL_METEORADAR : JSON_URL_MAIN;
  http.begin(client, currentURL);
  int httpCode = http.GET();

  String statHTML = "";

  // Statistiky se zobrazují pouze pokud není vybrán meteoradar
  if (strcmp(selectedParameter, "meteoradar") != 0 && httpCode > 0) {
    String payload = http.getString();
    DynamicJsonDocument doc(8192);
    DeserializationError err = deserializeJson(doc, payload);
    if (!err) {
      JsonArray arr = doc.as<JsonArray>();
      const char* paramToUse = "h1";      // výchozí parametr je teplota
      String paramLabel = "teplotu";      // popisek pro statistiku

      // Nastavení podle vybraného parametru
      if (strcmp(selectedParameter, "h2") == 0) {
        paramToUse = "h2";
        paramLabel = "vlhkost";
      } else if (strcmp(selectedParameter, "h3") == 0) {
        paramToUse = "h3";
        paramLabel = "tlak";
      } else if (strcmp(selectedParameter, "h4") == 0) {
        paramToUse = "h4";
        paramLabel = "prašnost";
      }

      // Výpočet statistik a odpovídajících barev
      StatColor sc = calculateStatsAndColors(arr, paramToUse);

      // HTML s barevně zvýrazněnými statistikami a jiným fontem
      statHTML = "<div style='max-width:380px; margin:20px auto; font-family: Verdana, Geneva, Tahoma, sans-serif;'>";
      statHTML += "<h3>Statistiky pro " + paramLabel + "</h3>";
      statHTML += "<p style='color:#333; font-weight: normal;'>";
      statHTML += "Minimální hodnota: <span style='color:" + colorToHex(sc.minColor) + "; font-weight: bold;'>" + String(sc.minValue, 2) + "</span><br>";
      statHTML += "Průměrná hodnota: <span style='color:" + colorToHex(sc.avgColor) + "; font-weight: bold;'>" + String(sc.avgValue, 2) + "</span><br>";
      statHTML += "Maximální hodnota: <span style='color:" + colorToHex(sc.maxColor) + "; font-weight: bold;'>" + String(sc.maxValue, 2) + "</span>";
      statHTML += "</p></div>";
    }
  }
  http.end();

  // HTML stránka s formulářem a vloženými statistikami (pokud jsou)
/* Formulář pro nastavení WiFi, parametru, jasu, intervalu apod. */
  String page = R"rawliteral(
<!DOCTYPE html>
<html lang="cs">
<head>
<meta charset="UTF-8" />
<meta name="viewport" content="width=device-width, initial-scale=1" />
<title>LaskaKit LED Config</title>
<style>
  body { font-family: 'Segoe UI', 'Arial', sans-serif; background: #f0f4f8; margin:0; padding:30px; }
  h2 { color: #0073e6; text-align: center; margin-bottom:25px; }
  form { max-width: 380px; margin: auto; background: #fff; border-radius:10px; padding:24px; box-shadow: 0 4px 36px rgba(0,45,100,0.10);}
  label { font-weight:600; display:block; margin-top:13px; }
  input, select { width:100%; padding:11px; margin-top:6px; border-radius:6px; border:1px solid #aaa; font-size:17px; }
  input[type=submit] { background: #0073e6; color: #fff; border:none; margin-top:26px; font-size:18px; cursor:pointer; transition:background 0.2s; }
  input[type=submit]:hover { background: #005bb5;}
  .footer { text-align: center; margin-top: 40px; color: #888; font-size:14px;}
  @media (max-width:470px) { form { padding:12px;} body { padding:8px;} }
</style>
</head>
<body>
  <h2>Nastavení LaskaKit LED Mapy ČR</h2>
  <form action="/save" method="post">
    <label for="ssid">WiFi SSID:</label>
    <input type="text" id="ssid" name="ssid" value="%SSID%" required />
    <label for="password">WiFi heslo:</label>
    <input type="password" id="password" name="password" placeholder="Nezadávej pokud nechceš měnit" value="" autocomplete="new-password" />
    <label for="param">Zobrazovaný parametr:</label>
    <select id="param" name="param">
      <option value="h1" %H1_SELECTED%>Teplota (Temperature)</option>
      <option value="h2" %H2_SELECTED%>Vlhkost (Humidity)</option>
      <option value="h3" %H3_SELECTED%>Tlak (Pressure)</option>
      <option value="h4" %H4_SELECTED%>Prášnost (Dustiness)</option>
      <option value="meteoradar" %METEORADAR_SELECTED%>Meteoradar (Srážky)</option>
    </select>
    <label for="brightness">Jas LED (0-255):</label>
    <input type="number" id="brightness" name="brightness" min="0" max="255" value="%BRIGHTNESS%" required />
    <label for="update">Interval aktualizace (sec):</label>
    <input type="number" id="update" name="update" min="10" max="3600" value="%UPDATE%" required />
    <input type="submit" value="Uložit a restartovat" />
  </form>
)rawliteral";

  // Nahrazení zástupných hodnot aktuálními daty
  page.replace("%SSID%", String(storedSSID));
  page.replace("%BRIGHTNESS%", String(brightness));
  page.replace("%UPDATE%", String(timerDelay / 1000));
  page.replace("%H1_SELECTED%", (strcmp(selectedParameter, "h1") == 0) ? "selected" : "");
  page.replace("%H2_SELECTED%", (strcmp(selectedParameter, "h2") == 0) ? "selected" : "");
  page.replace("%H3_SELECTED%", (strcmp(selectedParameter, "h3") == 0) ? "selected" : "");
  page.replace("%H4_SELECTED%", (strcmp(selectedParameter, "h4") == 0) ? "selected" : "");
  page.replace("%METEORADAR_SELECTED%", (strcmp(selectedParameter, "meteoradar") == 0) ? "selected" : "");

  // Přidání části se statistikami (pokud nejsou meteoradar)
  page += statHTML;

  page += R"rawliteral(
  <div class="footer">LaskaKit &copy; 2025 — WiFi konfigurace je dostupná vždy na této adrese zařízení.</div>
</body>
</html>
)rawliteral";

  // Odeslání výsledné webové stránky
  server.send(200, "text/html; charset=UTF-8", page);
}

void handleSave() {
  // Uložení nastavení z webového formuláře
  if (server.hasArg("ssid") && server.hasArg("param") && server.hasArg("brightness") && server.hasArg("update")) {
    String newSSID = server.arg("ssid");
    String newPassword = server.arg("password");
    String newParam = server.arg("param");
    int newBrightness = server.arg("brightness").toInt();
    int newUpdate = server.arg("update").toInt();

    bool restartNeeded = false;

    // Restart je potřeba pokud se změní SSID nebo heslo WiFi
    if (newSSID != String(storedSSID)) {
      restartNeeded = true;
      preferences.putString(KEY_SSID, newSSID);
      newSSID.toCharArray(storedSSID, sizeof(storedSSID));
    }

    if (newPassword.length() > 0) {
      restartNeeded = true;
      preferences.putString(KEY_PASS, newPassword);
      newPassword.toCharArray(storedPassword, sizeof(storedPassword));
    }

    // Pokud se změní parametr, uloží se a aktualizují se LED ihned
    if (newParam != String(selectedParameter)) {
      preferences.putString(KEY_PARAM, newParam);
      newParam.toCharArray(selectedParameter, sizeof(selectedParameter));
      fetchAndDisplayData();
    }

    // Změna jasu LED bez restartu
    if (newBrightness != brightness) {
      preferences.putInt(KEY_BRIGHT, newBrightness);
      brightness = newBrightness;
      strip.setBrightness(brightness);
      strip.show();
    }

    // Změna intervalu aktualizace bez restartu
    if (newUpdate != (timerDelay / 1000)) {
      preferences.putInt(KEY_UPDATE, newUpdate);
      timerDelay = newUpdate * 1000UL;
    }

    // Odeslání potvrzení, pokud je potřeba restart, za 2 sekundy restart
    if (restartNeeded) {
      String message =
        "<!DOCTYPE html>"
        "<html lang='cs'>"
        "<head>"
        "<meta charset='UTF-8'>"
        "<meta name='viewport' content='width=device-width, initial-scale=1'>"
        "<title>Nastavení uloženo</title>"
        "<style>"
        "body { font-family: 'Segoe UI', Arial, sans-serif; background: #f0f4f8; text-align: center; padding: 32px; }"
        "h2 { color: #0073e6; }"
        "</style>"
        "</head>"
        "<body>"
        "<h2>Nastavení uloženo. Restartuje se zařízení...</h2>"
        "</body></html>";

      server.send(200, "text/html; charset=UTF-8", message);
      delay(2000);
      ESP.restart();
    } else {
      // Odeslání potvrzení bez restartu s možností návratu na konfiguraci
      String message =
        "<!DOCTYPE html>"
        "<html lang='cs'>"
        "<head>"
        "<meta charset='UTF-8'>"
        "<meta name='viewport' content='width=device-width, initial-scale=1'>"
        "<title>Nastavení uloženo</title>"
        "<style>"
        "body { font-family: 'Segoe UI', Arial, sans-serif; background: #f0f4f8; text-align: center; padding: 32px; }"
        "h2 { color: #0073e6; }"
        ".back-btn { margin-top:24px; padding:12px 36px; font-size:17px; border-radius:7px; background:#0073e6; color:#fff; border:none; cursor:pointer; transition:background 0.2s; }"
        ".back-btn:hover { background:#005bb5; }"
        "</style>"
        "</head>"
        "<body>"
        "<h2>Nastavení uloženo.</h2>"
        "<form action='/' method='get'>"
        "<button class='back-btn' type='submit'>Zpět na konfiguraci</button>"
        "</form>"
        "</body></html>";

      server.send(200, "text/html; charset=UTF-8", message);
    }
  } else {
    server.send(400, "text/plain; charset=UTF-8", "Chybějící parametry.");
  }
}

void handleNotFound() {
  // Vypsání chyby při požadavku na neznámou stránku
  server.send(404, "text/plain; charset=UTF-8", "Stránka nenalezena");
}

void fetchAndDisplayData() {
  // Nastavení jasu LED pásku dle uložené hodnoty
  strip.setBrightness(brightness);

  // URL vybraných dat podle parametru
  String currentURL = JSON_URL_MAIN;
  if (strcmp(selectedParameter, "meteoradar") == 0) {
    currentURL = JSON_URL_METEORADAR;
  }

  WiFiClient client;
  HTTPClient http;
  http.begin(client, currentURL);
  int httpResponseCode = http.GET();

  if (httpResponseCode > 0) {
    String payload = http.getString();

    DynamicJsonDocument doc(8192);
    DeserializationError error = deserializeJson(doc, payload);
    if (error) {
      Serial.print(F("Chyba parsování JSON: "));
      Serial.println(error.f_str());
      return;
    }

    // Speciální zpracování pro meteoradar, kde barvy LED definují srážky
    if (strcmp(selectedParameter, "meteoradar") == 0) {
      Serial.println("Zobrazuji meteoradar");
      strip.clear();
      JsonArray mesta = doc["seznam"].as<JsonArray>();
      for (JsonObject mesto : mesta) {
        int id = mesto["id"];
        int r = mesto["r"];
        int g = mesto["g"];
        int b = mesto["b"];

#ifdef jednoducheZobrazeni
        if ((r > g) && (r > b))
          strip.setPixelColor(id, strip.Color(r, 0, 0));
        else if ((g > r) && (g > b))
          strip.setPixelColor(id, strip.Color(0, g, 0));
        else if ((b > r) && (b > g))
          strip.setPixelColor(id, strip.Color(0, 0, b));
#else
        strip.setPixelColor(id, strip.Color(r, g, b));
#endif
      }
      strip.show();
    } else {
      // Standardní zpracování JSON dat pro teplotu, vlhkost, tlak, prašnost
      float maxValue = -999999;
      float minValue = 999999;

      for (JsonObject item : doc.as<JsonArray>()) {
        int districtIndex = item["id"];
        districtIndex -= 1;
        if (item.containsKey(selectedParameter)) {
          float val = item[selectedParameter];
          TMEPDistrictValues[districtIndex] = val;
          if (val < minValue) minValue = val;
          if (val > maxValue) maxValue = val;
        } else {
          TMEPDistrictValues[districtIndex] = 0.0;
        }
      }

      // Nastavení barvy LED podle hodnoty daného okresu převedené ze škály HSV
      for (int LED = 0; LED < LEDS_COUNT; LED++) {
        int districtIdx = TMEPDistrictPosition[LED];
        float val = TMEPDistrictValues[districtIdx];
        color = map(val, minValue, maxValue, 170, 0);
        strip.setPixelColor(LED, strip.ColorHSV(color * 256));
      }
      strip.show();
    }
  } else {
    Serial.print("HTTP GET selhal, kód: ");
    Serial.println(httpResponseCode);
  }
  http.end();
}

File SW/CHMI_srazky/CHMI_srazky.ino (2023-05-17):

/*
* Program pro zobrazeni srazek z radaru CHMI pro 
* interaktivni RGB mapu Ceske republiky - https://www.laskakit.cz/laskakit-interaktivni-mapa-cr-ws2812b/
* a 
* mapa  tvoje___mama - https://github.com/tomasbrincil/pcb_mapa_cr_1
*
* Puvodnim autorem kodu je Jakub Cizek (zive.cz) - https://twitter.com/pesvkloubouku
* https://github.com/jakubcizek/pojdmeprogramovatelektroniku/tree/master/SrazkovyRadar
* https://www.zive.cz/clanky/naprogramovali-jsme-radarovou-mapu-ceska-ukaze-kde-prave-prsi-a-muzete-si-ji-dat-i-na-zed/sc-3-a-222111/default.aspx
*
* Dale upraveno:
* Alan Hodinar - https://twitter.com/alistaarec
* https://github.com/alistaarec/pcb_mapa_cr_1/blob/main/src/src_chmi.cpp
* pridano: podpora ESP8266, mapaTvojiMamy (Tomas Brincil), TMEP json
*
* LaskaKit.cz - https://twitter.com/laska_kit
* pridano: moznost jednoducheho zobrazeni (pouze cervena, zelena, modra), 
* podpora animace (zobrazeni pred 30min, 20min, 10min a aktualni s volitelnym zpozdenim), volba mezi LaskaKit mapou a MapaTvojiMamy
*
*/

#include <Arduino.h>
#include <Adafruit_NeoPixel.h>
#include <ArduinoJson.h>

#ifdef ESP8266
#include <ESP8266HTTPClient.h>
#include <ESP8266WiFi.h>
#endif

#ifdef ESP32
#include <HTTPClient.h>
#include <WiFi.h>
#endif

/*-------------------------------------*/
/*------------- KONFIGURACE -----------*/
/*-------------------------------------*/
//SSID a Heslo k WiFi
const char *ssid = "SSID";
const char *heslo = "HESLO";

#ifdef ESP8266
#define LEDPin 5 // datovy pin LED pro ESP8266
#endif

#ifdef ESP32
#define LEDPin 25 // datovy pin LED pro ESP32, pouziva LaskaKit mapa
#endif

unsigned long lastmill = 0;   
unsigned long timeout = 60000;  //60000 - aktualizace každou minutu
int jas = 10;

// Vyber zdrojoveho JSON souboru, odkomentuj pouze jeden
//#define URL1
#define URL2

// Vyber mapy, odkomentuje pouze jeden
#define laskakit
//#define mapaTvojiMamy

// Animace radarovych srazek, podporovano pouze z TMEP.cz, odkomentuj pokud ma byt povoleno
#define animace
#define animaceZpozdeni 1500 //zpozdeni mezi jednotlivymi JSON soubory v ms

// Zobrazeni pouze cervena, modra, zelena, odkomentuj pokud ma byt povoleno
#define jednoducheZobrazeni

/*-------------------------------------*/
/*---------- KONEC KONFIGURACE --------*/
/*-------------------------------------*/

#ifdef URL1
const char *DataURL = "http://oracle-ams.kloboukuv.cloud/radarmapa/?chcu=posledni.json";
#endif
#ifdef URL2
const char *DataURL = "http://tmep.cz/app/export/okresy-srazky-laskakit.json";
#endif
// animace radaru po 10 minutach (pouze TMEP.cz)
#if defined(animace) && defined(URL2)
const char *DataURL30 = "http://tmep.cz/app/export/okresy-srazky-laskakit-30.json";
const char *DataURL20 = "http://tmep.cz/app/export/okresy-srazky-laskakit-20.json";
const char *DataURL10 = "http://tmep.cz/app/export/okresy-srazky-laskakit-10.json";
#endif

//Prevod ID pro mapu tvoje___mama
int MapaTvojiMamy[72] = {
9, 11, 12, 8, 10, 13, 6, 15, 7, 5, 3, 14, 16, 67, 66, 4, 2, 24, 17, 1,
68, 18, 65, 64 ,0, 25, 76, 20, 69, 19, 27, 23, 73, 70, 21, 29, 28, 59, 
22, 71, 61, 63, 30, 72, 31, 26, 48, 46, 33, 39, 58, 49, 51, 47, 57, 40, 
32, 35, 56 ,38, 55, 34, 45, 41, 50, 36, 54, 52 ,37, 44, 53, 43

};

Adafruit_NeoPixel mapLed(77, LEDPin, NEO_GRB + NEO_KHZ800);

StaticJsonDocument<10000> doc;

int jsonDecoder(String s, bool log) {
  DeserializationError e = deserializeJson(doc, s);
  int fid;
  int idMama;
  if (e) {
    if (e == DeserializationError::InvalidInput) {
      return -1;
    } else if (e == DeserializationError::NoMemory) {
      return -2;
    } else {
      return -3;
    }
  } else {
    mapLed.clear();
    JsonArray mesta = doc["seznam"].as<JsonArray>();
    for (JsonObject mesto : mesta) {
      int id = mesto["id"];
      int r = mesto["r"];
      int g = mesto["g"];
      int b = mesto["b"];

#ifdef laskakit
  fid = id;
#endif
#ifdef mapaTvojiMamy
  idMama = MapaTvojiMamy[id];
  fid = idMama;
#endif
       
      if (log) Serial.printf("Rozsvecuji mesto %d barvou R=%d G=%d B=%d", id, r, g, b);
      Serial.printf("  ---IDLaska %d --- IDMama %d --- FinalID %d\r\n", id, idMama, fid);

#ifdef jednoducheZobrazeni
      if((r > g) && (r > b))
        mapLed.setPixelColor(fid, mapLed.Color(r, 0, 0));
      else if((g > r) && (g > b))
        mapLed.setPixelColor(fid, mapLed.Color(0, g, 0));
      else if((b > r) && (b > g))
        mapLed.setPixelColor(fid, mapLed.Color(0, 0, b));
      
#ifdef mapaTvojiMamy
      // MapaTvojiMamy ma vice LED, fix rozdilu
      switch (id) {
        case 63: 
          if((r > g) && (r > b))
            mapLed.setPixelColor(42, mapLed.Color(r, 0, 0));
          else if((g > r) && (g > b))
            mapLed.setPixelColor(42, mapLed.Color(0, g, 0));
          else if((b > r) && (b > g))
            mapLed.setPixelColor(42, mapLed.Color(0, 0, b));
              break;
        case 26:
          if((r > g) && (r > b))
            mapLed.setPixelColor(74, mapLed.Color(r, 0, 0));
          else if((g > r) && (g > b))
            mapLed.setPixelColor(74, mapLed.Color(0, g, 0));
          else if((b > r) && (b > g))
            mapLed.setPixelColor(74, mapLed.Color(0, 0, b));

          if((r > g) && (r > b))
            mapLed.setPixelColor(75, mapLed.Color(r, 0, 0));
          else if((g > r) && (g > b))
            mapLed.setPixelColor(75, mapLed.Color(0, g, 0));
          else if((b > r) && (b > g))
            mapLed.setPixelColor(75, mapLed.Color(0, 0, b));
          break;
        case 40:
          if((r > g) && (r > b))
            mapLed.setPixelColor(60, mapLed.Color(r, 0, 0));
          else if((g > r) && (g > b))
            mapLed.setPixelColor(60, mapLed.Color(0, g, 0));
          else if((b > r) && (b > g))
            mapLed.setPixelColor(60, mapLed.Color(0, 0, b));
          if((r > g) && (r > b))
            mapLed.setPixelColor(62, mapLed.Color(r, 0, 0));
          else if((g > r) && (g > b))
            mapLed.setPixelColor(62, mapLed.Color(0, g, 0));
          else if((b > r) && (b > g))
            mapLed.setPixelColor(62, mapLed.Color(0, 0, b));
          break;
      }
#endif //mapaTvojiMamy
#else
      mapLed.setPixelColor(fid, mapLed.Color(r, g, b));
#ifdef mapaTvojiMamy
      // MapaTvojiMamy ma vice LED, fix rozdilu
      switch (id) {
        case 63: 
          mapLed.setPixelColor(42, mapLed.Color(r, g, b));
          break;
        case 26:
          mapLed.setPixelColor(74, mapLed.Color(r, g, b));
          mapLed.setPixelColor(75, mapLed.Color(r, g, b));
          break;
        case 40:
          mapLed.setPixelColor(60, mapLed.Color(r, g, b));
          mapLed.setPixelColor(62, mapLed.Color(r, g, b));
          break;
      }
#endif //mapaTvojiMamy
#endif //jednoducheZobrazeni
    }
    mapLed.show();
    return 0;
  }
}
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

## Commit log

2023-03-15 small update
    [mapa_cr_bom.csv, mapa_cr_bottom_bom.csv, mapa_cr_top_bom.csv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]
2023-04-14 BOM changes
    [mapa_cr_top_bom.csv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]
2023-04-23 Update tmep_okresy-cr-teplota.ino
    Add the possibility of variable color layout (based on min and max temperature in Czechia) instead of fixed min and max (-15 - 40°C)
    [tmep_okresy-cr-teplota.ino]
2023-05-27 new data
    [mapa_cr_bottom_bom.csv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]
